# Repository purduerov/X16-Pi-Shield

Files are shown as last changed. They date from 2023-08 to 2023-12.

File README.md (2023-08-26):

# Readme for X16-Pi-Shield
This board powers the Raspberry Pi and connects sensors to the Pi

Whenever you make a new part, download the datasheet and save it here _**and**_ with the part in the parts library

Always pull other people's changes before beginning to work
`git pull`

Be sure to push your changes after  working on them. Run:
1. `git add .` to add any files in this directory or a subdirectory
or `git add -u` to add any modified files
2. (Optional) `git clean -nX` to see what ignored files can be removed
	`git clean -fX` removes ignored files (Eagle backups)
3. `git commit -m "helpful commit message"` with a description of the work that you did
4. `git push` to push your work to github

Other helpful commands
* `git status` says information about modified and staged files
* `git log` shows the recent commits of the repository
* `git log filename.extension` show the recent commits for just that file
* `git checkout first-couple-letter-of-commit-id` lets you go back to a previous version
* `git checkout master` brings you back to the latest commit
* `git tag` lists the tags
* `git tag -a orderX -m "the version of the board placed for the X'th order"` tag a specific commit
* `git push --tags` needed to push tags to remote
* `git show orderX` show the commit log for the given tag
* `git checkout orderX` go back and interact with the files at the tagged commit

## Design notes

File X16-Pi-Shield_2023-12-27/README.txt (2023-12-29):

File Descriptions:
X16-Pi-Shield.GBL - Bottom Copper Layer                        
X16-Pi-Shield.GBO - Bottom Silkscreen/Overlay
X16-Pi-Shield.GBS - Bottom Solder Mask
X16-Pi-Shield.GBP - Bottom Paste Mask
X16-Pi-Shield.GTL - Top Copper Layer
X16-Pi-Shield.GTO - Top Silkscreen/Overlay
X16-Pi-Shield.GTS - Top Solder Mask
X16-Pi-Shield.GTP - Top Paste Mask
X16-Pi-Shield.GKO - Keep Out Layer(Board Outline)
X16-Pi-Shield.XLN - Excellon Drill File

Contact Information:
Name: Minh Nguyen
Email (Preferred): nguye599@purdue.edu
Phone: 4059079922

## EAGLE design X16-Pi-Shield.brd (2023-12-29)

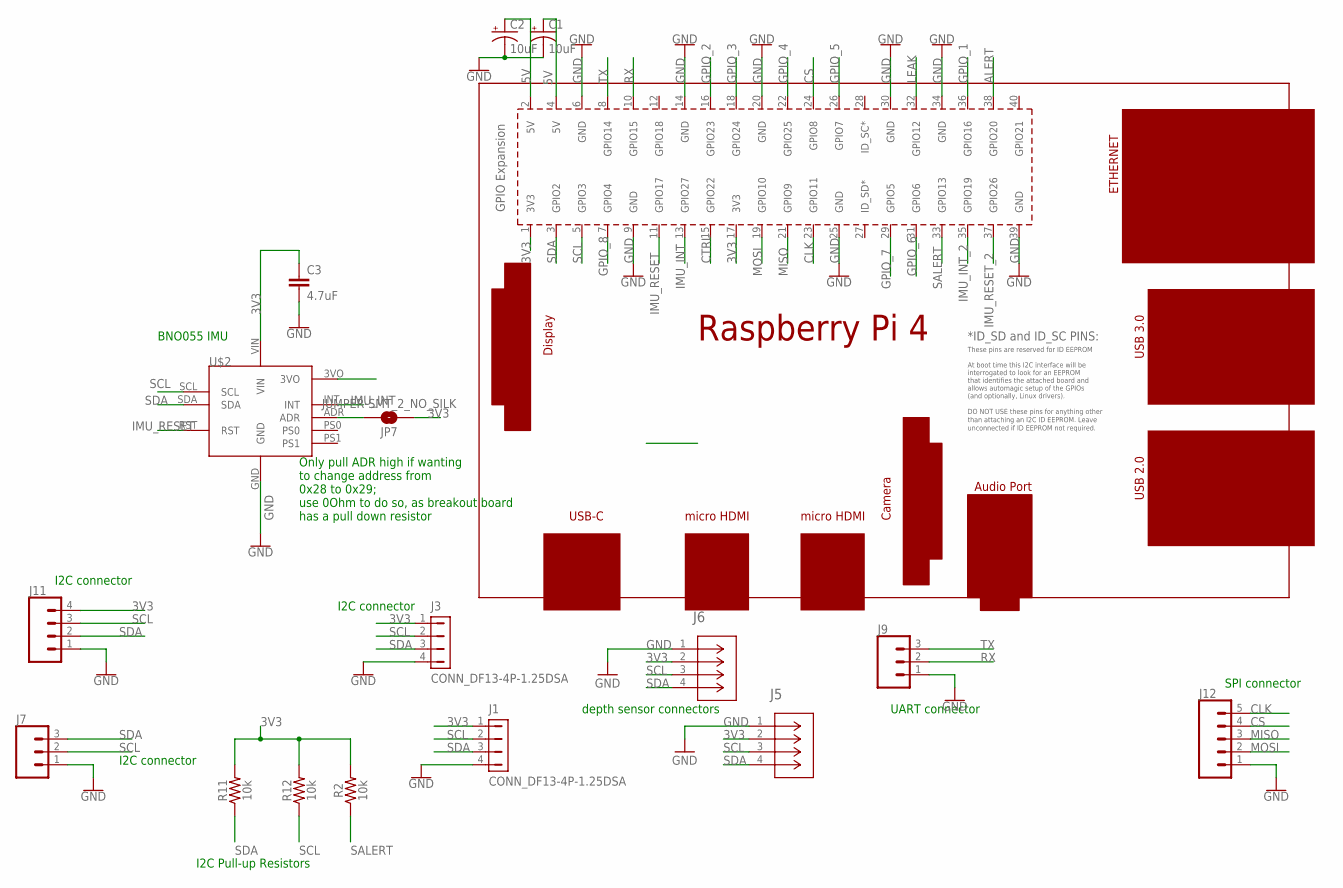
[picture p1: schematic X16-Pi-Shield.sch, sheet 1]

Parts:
C1, C2: 10uF; 0603-POLAR
C3: 4.7uF; 0603
J1, J3: CONN_DF13-4P-1.25DSA; DF13-4P-1.25DSA
J5, J6: BM04B-GHS-TBT; CONN_BM04B-GHS-TBT_JST
J7, J9: CONN_03; 1X03
J11: CONN_04; 1X04
J12: CONN_05; 1X05
JP7: JUMPER-SMT_2_NO_SILK; SMT-JUMPER_2_NO_SILK
R2, R11, R12: 10k; 0603
U$1: RPI4
U$2: CONN_ADAFRUIT-BNO055; ADAFRUIT-BNO055

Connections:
3V3: C3.1, J1.1, J3.1, J5.2, J6.2, J11.4, JP7.1, R2.2, R11.2, R12.2, U$1.1 (3V3), U$1.17 (3V3), U$2.VIN; also elsewhere on the board
5V: C1.+, C2.+, U$1.2 (5V), U$1.4 (5V); also elsewhere on the board
ALERT: U$1.38 (GPIO20); also elsewhere on the board
CLK: J12.5, U$1.23 (GPIO11); also elsewhere on the board
CS: J12.4, U$1.24 (GPIO8); also elsewhere on the board
CTRL: U$1.15 (GPIO22); also elsewhere on the board
GND: C1.-, C2.-, C3.2, J1.4, J3.4, J5.1, J6.1, J7.1, J9.1, J11.1, J12.1, U$1.6 (GND), U$1.9 (GND), U$1.14 (GND), U$1.20 (GND), U$1.25 (GND), U$1.30 (GND), U$1.34 (GND), U$1.39 (GND), U$2.GND; also elsewhere on the board
GPIO_1: U$1.36 (GPIO16); also elsewhere on the board
GPIO_2: U$1.16 (GPIO23); also elsewhere on the board
GPIO_3: U$1.18 (GPIO24); also elsewhere on the board
GPIO_4: U$1.22 (GPIO25); also elsewhere on the board
GPIO_5: U$1.26 (GPIO7); also elsewhere on the board
GPIO_6: U$1.31 (GPIO6); also elsewhere on the board
GPIO_7: U$1.29 (GPIO5); also elsewhere on the board
GPIO_8: U$1.7 (GPIO4); also elsewhere on the board
IMU_INT: U$1.13 (GPIO27), U$2.INT
IMU_INT_2: U$1.35 (GPIO19); also elsewhere on the board
IMU_RESET: U$1.11 (GPIO17), U$2.RST
IMU_RESET_2: U$1.37 (GPIO26); also elsewhere on the board
LEAK: U$1.32 (GPIO12); also elsewhere on the board
MISO: J12.3, U$1.21 (GPIO9); also elsewhere on the board
MOSI: J12.2, U$1.19 (GPIO10); also elsewhere on the board
unnamed: JP7.2, U$2.ADR
RX: J9.2, U$1.10 (GPIO15)
SALERT: R2.1, U$1.33 (GPIO13); also elsewhere on the board
SCL: J1.2, J3.2, J5.3, J6.3, J7.2, J11.3, R12.1, U$1.5 (GPIO3), U$2.SCL; also elsewhere on the board
SDA: J1.3, J3.3, J5.4, J6.4, J7.3, J11.2, R11.1, U$1.3 (GPIO2), U$2.SDA; also elsewhere on the board
TX: J9.3, U$1.8 (GPIO14)

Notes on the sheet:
I2C Pull-up Resistors
BNO055 IMU
Only pull ADR high if wanting to change address from 0x28 to 0x29; use 0Ohm to do so, as breakout board has a pull down resistor
I2C connector
UART connector
SPI connector
depth sensor connectors

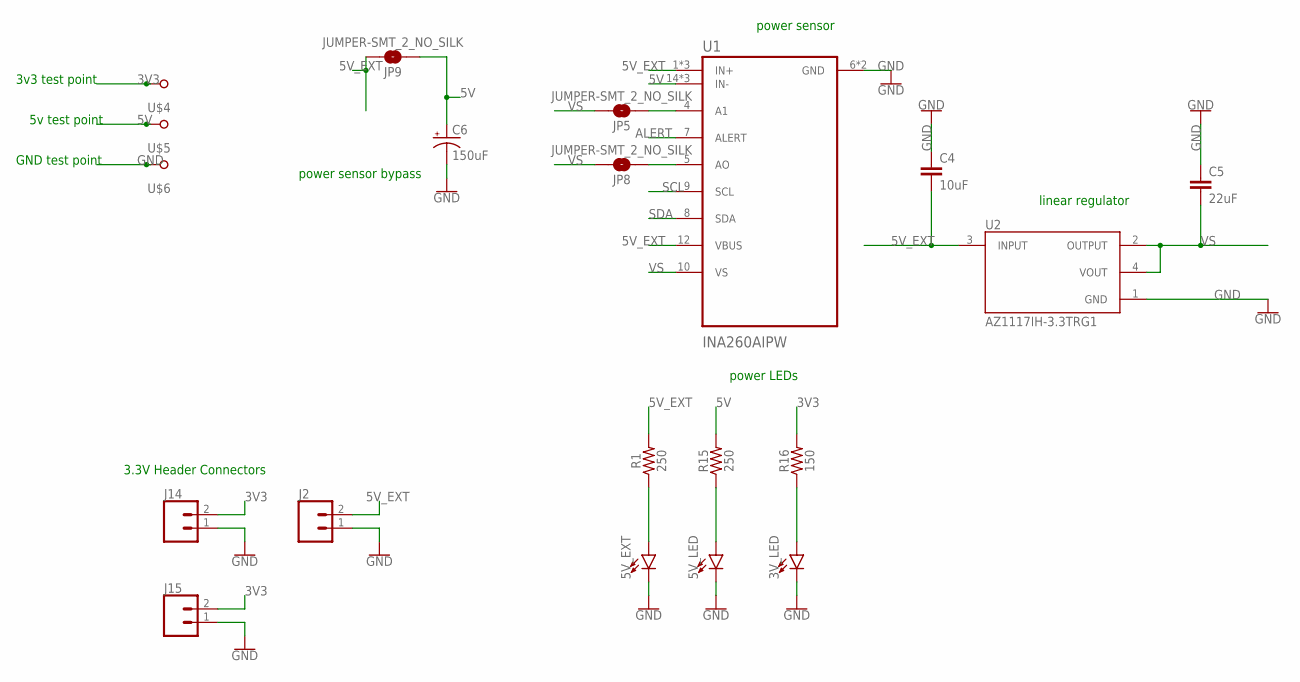
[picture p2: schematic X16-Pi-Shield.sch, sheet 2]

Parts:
3V_LED, 5V_EXT, 5V_LED: LEDCHIPLED_0805; CHIPLED_0805
C4: 10uF; 0603
C5: 22uF; 0603
C6: 150uF; 2917(7343-31-METRIC)
J2, J14, J15: CONN_02; 1X02
JP5, JP8, JP9: JUMPER-SMT_2_NO_SILK; SMT-JUMPER_2_NO_SILK
R1, R15: 250; 0603
R16: 150; 0603
U1: INA260AIPW; SOP65P640X120-16N
U2: AZ1117IH-3.3TRG1; SOT230P700X185-4N
U$4, U$5, U$6: TESTPOINT_5.04MM

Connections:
3V3: J14.2, J15.2, R16.2, U$4.TP; also elsewhere on the board
5V: C6.+, JP9.1, R15.2, U1.14 (IN-), U1.15 (IN-), U1.16 (IN-), U$5.TP; also elsewhere on the board
5V_EXT: C4.2, J2.2, JP9.2, R1.2, U1.1 (IN+), U1.2 (IN+), U1.3 (IN+), U1.12 (VBUS), U2.3 (INPUT); also elsewhere on the board
ALERT: U1.7 (ALERT); also elsewhere on the board
GND: 3V_LED.C, 5V_EXT.C, 5V_LED.C, C4.1, C5.1, C6.-, J2.1, J14.1, J15.1, U1.6 (GND), U1.11 (GND), U2.1 (GND), U$6.TP; also elsewhere on the board
unnamed: JP5.1, U1.4 (A1)
unnamed: JP8.1, U1.5 (AO)
unnamed: 5V_EXT.A, R1.1
unnamed: 5V_LED.A, R15.1
unnamed: 3V_LED.A, R16.1
SCL: U1.9 (SCL); also elsewhere on the board
SDA: U1.8 (SDA); also elsewhere on the board
VS: C5.2, JP5.2, JP8.2, U1.10 (VS), U2.2 (OUTPUT), U2.4 (VOUT)

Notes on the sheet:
power LEDs
3.3V Header Connectors
power sensor
linear regulator
power sensor bypass
3v3 test point
5v test point
GND test point

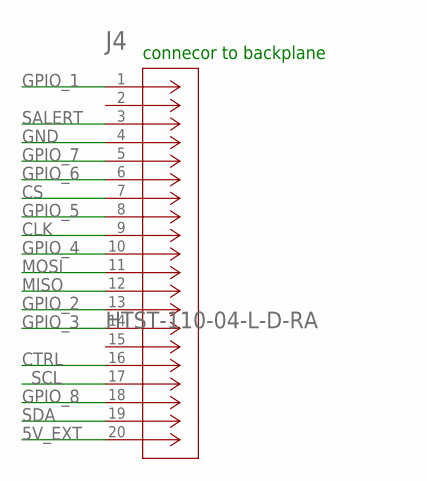
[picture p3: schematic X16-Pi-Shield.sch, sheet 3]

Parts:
J4: HTST-110-04-L-D-RA; CONN_HTST-110-04/05-X-D-RA_SAI

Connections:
5V_EXT: J4.20; also elsewhere on the board
CLK: J4.9; also elsewhere on the board
CS: J4.7; also elsewhere on the board
CTRL: J4.16; also elsewhere on the board
GND: J4.4; also elsewhere on the board
GPIO_1: J4.1; also elsewhere on the board
GPIO_2: J4.13; also elsewhere on the board
GPIO_3: J4.14; also elsewhere on the board
GPIO_4: J4.10; also elsewhere on the board
GPIO_5: J4.8; also elsewhere on the board
GPIO_6: J4.6; also elsewhere on the board
GPIO_7: J4.5; also elsewhere on the board
GPIO_8: J4.18; also elsewhere on the board
MISO: J4.12; also elsewhere on the board
MOSI: J4.11; also elsewhere on the board
SALERT: J4.3; also elsewhere on the board
SCL: J4.17; also elsewhere on the board
SDA: J4.19; also elsewhere on the board

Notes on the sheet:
connecor to backplane

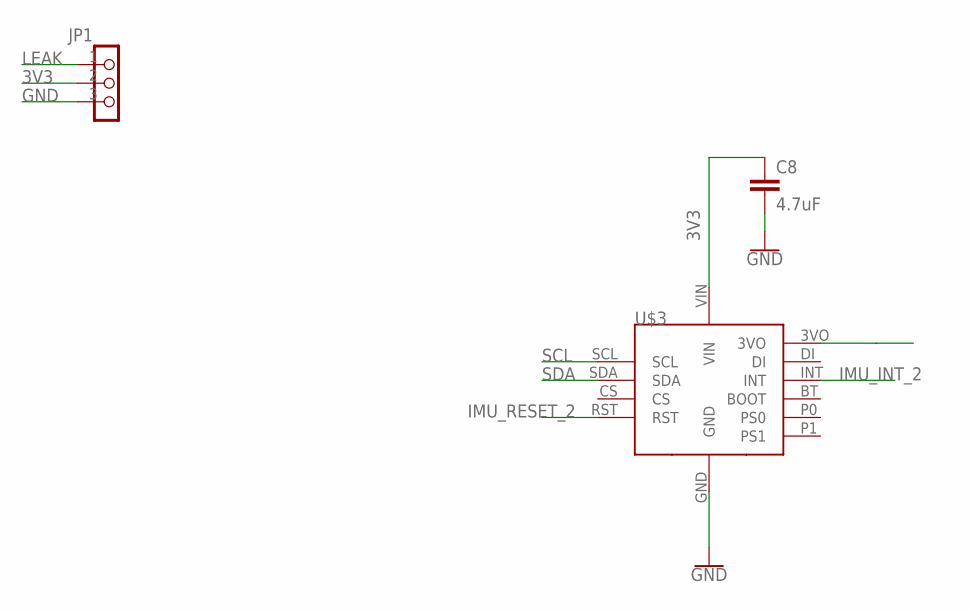
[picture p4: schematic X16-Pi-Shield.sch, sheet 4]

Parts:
C8: 4.7uF; 0603
JP1: TEST_PIN-1X3; 1X03
U$3: ADAFRUIT-BNO080

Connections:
3V3: C8.1, JP1.2, U$3.VIN; also elsewhere on the board
GND: C8.2, JP1.3, U$3.GND; also elsewhere on the board
IMU_INT_2: U$3.INT; also elsewhere on the board
IMU_RESET_2: U$3.RST; also elsewhere on the board
LEAK: JP1.1; also elsewhere on the board
SCL: U$3.SCL; also elsewhere on the board
SDA: U$3.SDA; also elsewhere on the board

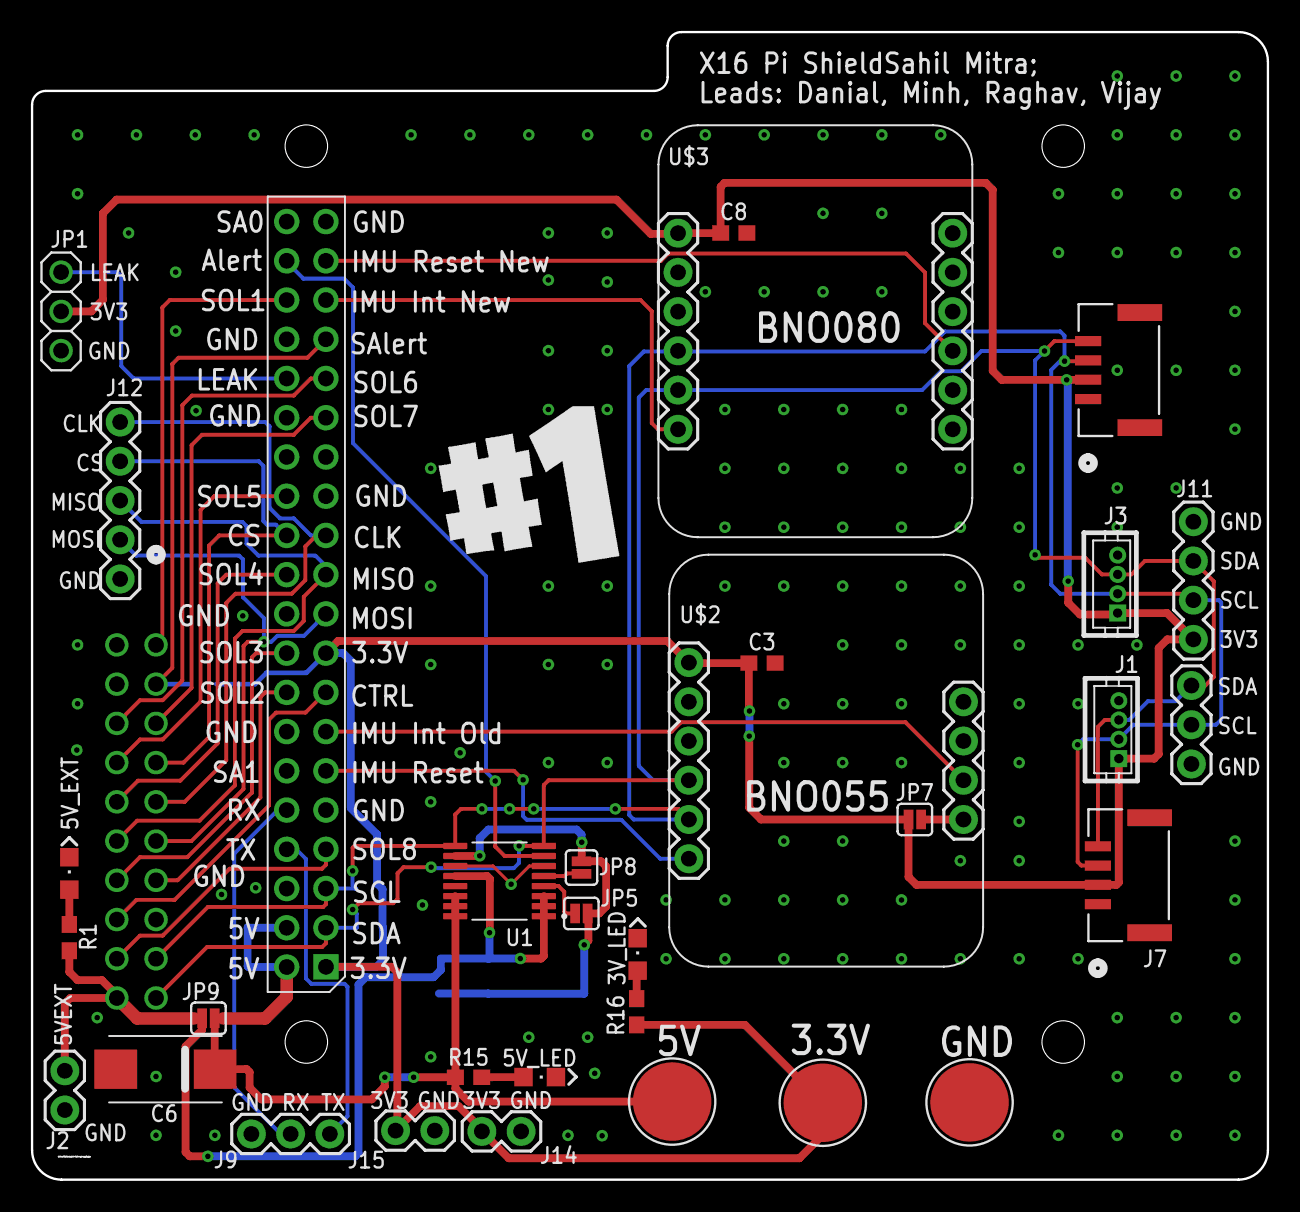
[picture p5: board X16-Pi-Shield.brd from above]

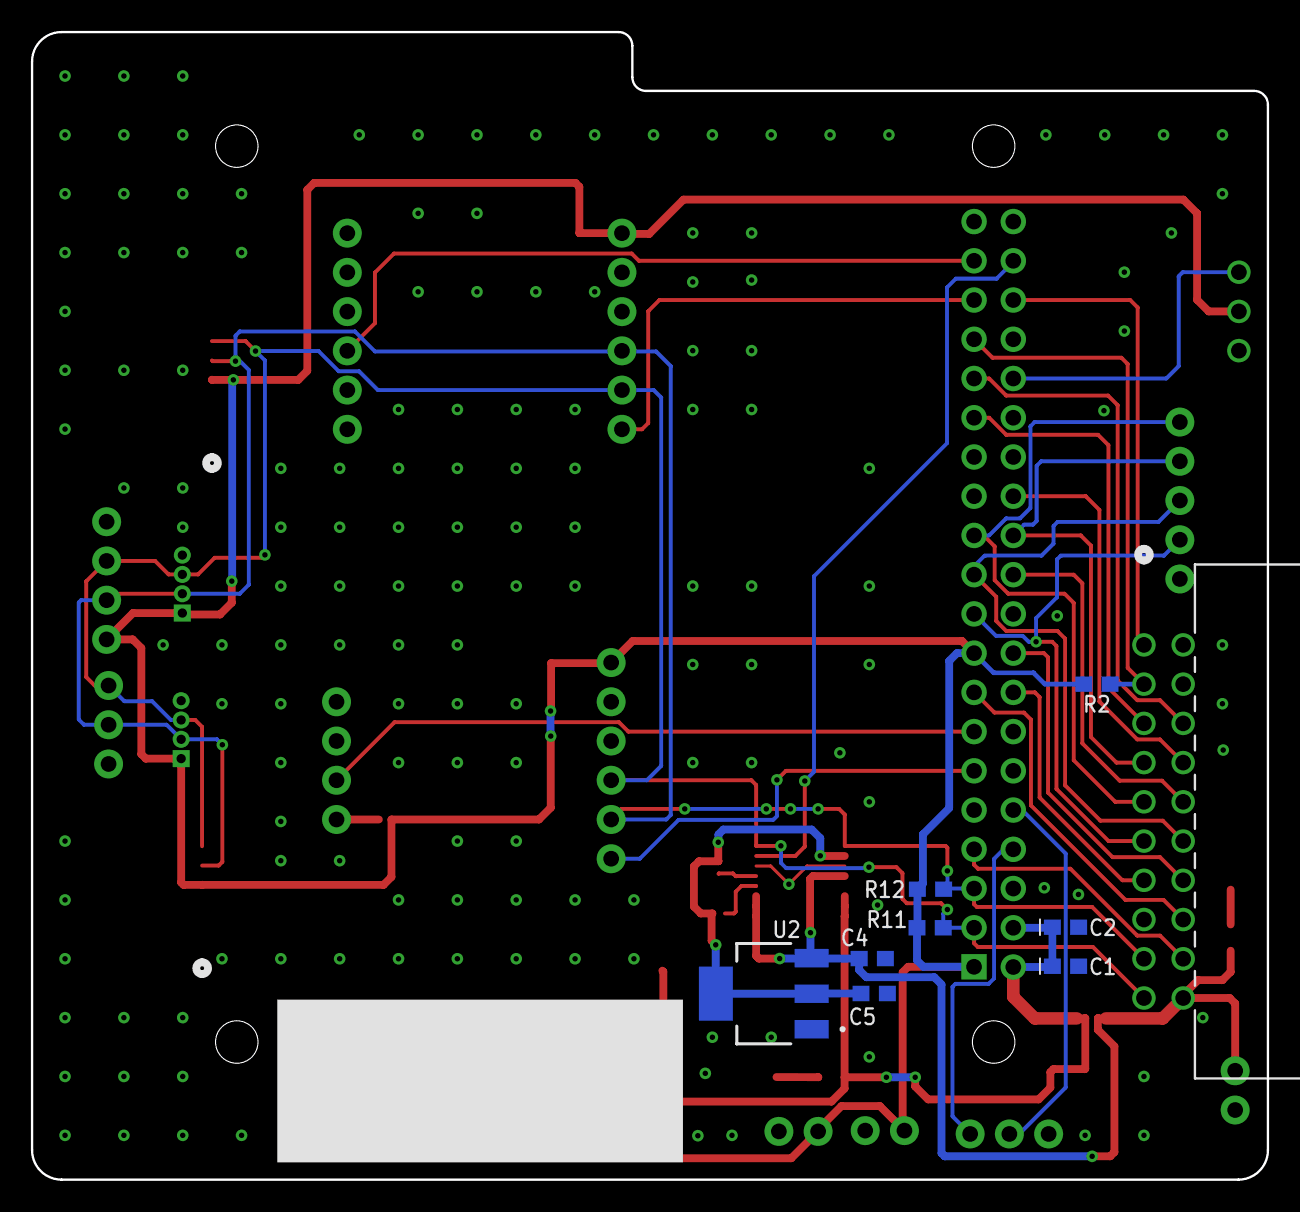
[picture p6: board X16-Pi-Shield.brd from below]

Board: 2 copper layers, 80.0 x 74.3 mm, 41 parts (9 on the bottom side), 35 nets.

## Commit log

2023-10-04 Added board dimensions
    [X16-Pi-Shield.brd]
2023-10-05 finished schematic(mostly)
    [X16-Pi-Shield.brd, X16-Pi-Shield.sch]
2023-10-11 added new board dimensions
    [X16-Pi-Shield.brd]
2023-10-14 completed schematic
    [X16-Pi-Shield.brd, X16-Pi-Shield.sch]
2023-10-14 edited schematic for new connector
    [X16-Pi-Shield.brd, X16-Pi-Shield.sch]
2023-10-14 added connector
    [X16-Pi-Shield.brd, X16-Pi-Shield.sch]
2023-10-14 added some nets
    [X16-Pi-Shield.brd, X16-Pi-Shield.sch]
2023-10-14 fixed library problems
    [X16-Pi-Shield.brd, X16-Pi-Shield.sch]
2023-10-14 made some changes
    [X16-Pi-Shield.brd, X16-Pi-Shield.sch]
2023-10-14 updated schematic and library
    [X16-Pi-Shield.brd, X16-Pi-Shield.sch]
2023-10-18 final schematic
    [X16-Pi-Shield.brd, X16-Pi-Shield.sch]
2023-10-21 started labeling schematic
    [X16-Pi-Shield.brd, X16-Pi-Shield.sch]
2023-10-21 updated schematuc with labels
    [X16-Pi-Shield.brd, X16-Pi-Shield.sch]
2023-11-04 removed unused components and added new imu
    [X16-Pi-Shield.brd, X16-Pi-Shield.sch]
2023-11-04 added new imu
    [X16-Pi-Shield.brd, X16-Pi-Shield.sch]
2023-11-11 updated connector footprint and connector connections
    [X16-Pi-Shield.brd, X16-Pi-Shield.sch]
2023-11-11 more traces
    [X16-Pi-Shield.brd]
2023-11-18 remade the board
    [X16-Pi-Shield.brd]
2023-12-06 remade board
    [X16-Pi-Shield.brd, X16-Pi-Shield.sch]
2023-12-08 finished board
    [X16-Pi-Shield.brd, X16-Pi-Shield.sch]
2023-12-20 Minh Update
    [X16-Pi-Shield.brd, X16-Pi-Shield.sch]
2023-12-20 Minh Update 2
    [X16-Pi-Shield.brd, X16-Pi-Shield.sch]
2023-12-21 Added resistor values. Make sure to update BOM!
    [X16-Pi-Shield.brd, X16-Pi-Shield.sch]
2023-12-22 Minh Update 3
    [X16-Pi-Shield.brd]
2023-12-27 Revert "Minh Update 3"
    This reverts commit ef018cd753ae75237427e996904381017dc6cda3.
    [X16-Pi-Shield.brd]
2023-12-27 Minh Update 4 - Edit PMBUS traces, and modify Label + Traces
    [X16-Pi-Shield.brd, X16-Pi-Shield.sch]
2023-12-29 Minh Update 5
    [X16-Pi-Shield.GBL, X16-Pi-Shield.GBO, X16-Pi-Shield.GBP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]

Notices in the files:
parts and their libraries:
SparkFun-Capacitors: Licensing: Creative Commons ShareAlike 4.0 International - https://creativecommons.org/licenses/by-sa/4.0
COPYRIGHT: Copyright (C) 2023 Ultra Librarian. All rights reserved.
